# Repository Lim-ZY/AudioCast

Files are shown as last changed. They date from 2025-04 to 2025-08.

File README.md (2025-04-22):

# AudioCast: Enabling Ubiquitous Connectivity for Embedded Systems through Audio-Broadcasting Low-power Tags

banner

## Overview

Wireless connectivity challenges hinder the deployment of embedded systems. We introduce AudioCast to address two critical issues: spectrum scarcity-induced contention and high power consumption in transmitters. The widespread availability of broadcast radio receivers (for example, FM radios using the 88–108 MHz spectrum) and access to underutilized lower-frequency spectrum motivate the design of AudioCast. The lower-frequency spectrum offers superior radio-wave propagation characteristics, exhibiting at least 10× lower path loss than the 2.4 GHz and 5 GHz Industrial, Scientific, and Medical (ISM) bands while avoiding congestion and interference. These properties enable reliable and long-distance communication, even for weakly radiated signals. AudioCast builds on these properties and the unique negative resistance of a tunnel diode.

AudioCast rethinks the architecture of radio transmitters using a tunnel diode oscillator to generate carrier signals and self-modulate them with baseband signals. This results in frequency-modulated transmissions at an overall power consumption below 200 μW. Unlike related systems based on the backscatter mechanism, AudioCast does not require an externally generated carrier or rely on ambient signals. We argue that AudioCast represents an example of a new class of transmitters which we conceptualize as Beyond-Backscatter transmitters. Through experiments, we demonstrate that AudioCast achieves a transmission range of up to 130 m in line-of-sight and tens of meters in non-line-of-sight conditions respectively. These transmissions are decodable by ubiquitous commodity FM receivers in cars, homes, and phones. We evaluate AudioCast through theoretical analysis, benchtop experiments, and urban/indoor field deployments. Additionally, we prototype and demonstrate novel applications, including low-power voice transmissions and hand gesture communication, enabled by AudioCast’s range and power efficiency.

## Repository Organization

```
├── LICENSE                
├── README.md
├── frequency_scanner         # Utility to scan unallocated FM frequencies
├── hardware                  # PCB hardware design files for baseband generator and frontend
├── assets                    # Images, videos, posters, etc.
└── transmitter_firmware      # Firmware code for baseband generator, FM tuner, etc.
```

## AudioCast System Preview

### FM Modulation vs Mixing

With increasing frequency of baseband / message signal, the value of the modulation index reduces and it becomes narrowband frequency modulation. A narrowband frequency modulation can be approximated as a mixing process, with upper sidebands becoming negligible which is shown in the following video:

https://github.com/user-attachments/assets/ccb81c37-590c-4e0f-b894-82cb153416e6

Alternatively: Watch it [here](https://www.youtube.com/watch?v=7RvvvsP36FI)

### Indoor NLoS Audio Evaluation

Non-line-of-sight (NLoS) evaluation of AudioCast transmitter, showing the transmitted audio snippets and corresponding received audio snippets at 7 different locations. We transmitted audio snippets of 30s but for the video we depict only 5s to make it brief. Furthermore, the calculated PESQ score for evaluating the received audio quality is also shown in the following video:

https://github.com/user-attachments/assets/ebbb9d8d-553b-4ae6-ada7-a8c252bf67cc

Alternatively: Watch it [here](https://www.youtube.com/watch?v=k4Gf5YFvplg)

> The above videos can also be previewed [here](./assets/videos/).

## Publications

1. [**ACM IMWUT (UbiComp) '25**](https://doi.org/10.1145/3729471) - *AudioCast: Enabling Ubiquitous Connectivity for Embedded Systems through Audio-Broadcasting Low-power Tags*
   > **Full paper** to appear in IMWUT - June '25: **Vol. 9, No. 2, Article 27** and to be presented at ACM UbiComp '25 in Espoo, Finland.
    <details>
    <summary>Click to expand citation</summary>

    ```
    @article{audiocast_imwut25,
        author = {Reddy, C. Rajashekar; Shah, Dhairya Jigar; Ang, Nobel and Varshney, Ambuj (to appear)},
        title = {AudioCast: Enabling Ubiquitous Connectivity for Embedded Systems through Audio-Broadcasting Low-power Tags},
        journal = {IMWUT},
        year = {2025},
        issue_date = {June 2025},
        publisher = {Association for Computing Machinery},
        address = {New York, NY, USA},
        volume = {9},
        number = {2},
        url = {https://doi.org/10.1145/3729471},
        doi = {10.1145/3729471},
        articleno = {27},
        numpages = {32},
    }
    ```

    </details>

 2. [**ACM MobiSys '25**](https://www.sigmobile.org/mobisys/2025/) - *Enabling Ubiquitous Connectivity for Embedded Systems through Audio-Broadcasting Low-power Tags*
    > **Demo** to appear at MobiSys '25 in Anaheim, California, US.
    <details>
    <summary>Click to expand citation</summary>

    ```
    @inproceedings{audiocast_mobisys25,
        author = {Reddy, C. Rajashekar and Shah, Dhairya Jigar and Varshney, Ambuj (to appear)},
        title = {Enabling Ubiquitous Connectivity for Embedded Systems through Audio-Broadcasting Low-power Tags},
        year = {2025},
        publisher = {Association for Computing Machinery},
        address = {New York, NY, USA},
        numpages = {2},
        location = {Anaheim, California, US},
        series = {MOBISYS '25}
    }
    ```
    </details>

 3. [**ACM ENSsys '23**](https://dl.acm.org/doi/10.1145/3628353.3628546) - *Beyond Broadcasting: Revisiting FM Frequency-band for Providing Connectivity to Next Billion Devices*
    > **Paper** presented at EnSsys '23 Workshop which has held in conjunction with ACM SenSys '23 in Istanbul, Turkey. AudioCast builds on this early work.
    <details>
    <summary>Click to expand citation</summary>
    
    ```
    @inproceedings{tunnelradio_enssys23,
        author = {Reddy, C. Rajashekar and Gulati, Manoj and Varshney, Ambuj},
        title = {Beyond Broadcasting: Revisiting FM Frequency-band for Providing Connectivity to Next Billion Devices},
        year = {2023},
        isbn = {9798400704383},
        publisher = {Association for Computing Machinery},
        address = {New York, NY, USA},
        url = {https://doi.org/10.1145/3628353.3628546},
        doi = {10.1145/3628353.3628546},
        booktitle = {Proceedings of the 11th International Workshop on Energy Harvesting \& Energy-Neutral Sensing Systems},
        pages = {30–36},
        numpages = {7},
        keywords = {FM communication, Internet of Things (IoT), Low-Power Communication, Tunnel Diodes},
        location = {Istanbul, Turkiye},
        series = {ENSsys '23}
    }
    ```

## Contributors and Team

AudioCast is developed and maintained by the following researchers from the [WEISER group](https://weiserlab.github.io/ambuj/) from the School of Computing, National University of Singapore (NUS). 

1. [C. Rajashekar Reddy](https://github.com/rez39)
2. [Dhairya Shah](https://github.com/dhairyashah1/)
3. [Prof. Ambuj Varshney](https://github.com/weiserlab/)

> Feel free to contact us at [`rajashekar.c@u.nus.edu`](mailto:rajashekar.c@u.nus.edu) or [`dhairya@u.nus.edu`](mailto:dhairya@u.nus.edu) for any questions or suggestions.

## Acknowledgements

We acknowledge Nobel Ang, [Yuvraj Singh Bhadauria](https://github.com/UvrajSB) and [Manoj Gulati](https://github.com/manojgulati) for their assistance and support during the early stages of this work.

## Funding

This research is fully supported by the Advanced Research and Technology Innovation Centre **(ARTIC)** at the National University of Singapore. In addition, some parts of this work are supported by a **Tier 1 grant** from Ministry of Education. It is also supported by a **Startup Grant** from ODPRT and an unrestricted gift from Google through their **Research Scholar Program**, all of which are hosted at the National University of Singapore (NUS).

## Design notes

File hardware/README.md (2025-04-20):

# Hardware Design Files

This folder contains PCB design files for the hardware: baseband generator and tunnel-diode oscillator frontend (TDO) used in AudioCast.

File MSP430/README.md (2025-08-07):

Connections from MSP430 to Si4713:

External Pullup Resistors required for I2C

MSP430 -> Si4713

Data: P1.2 -> LIN/RIN

SDA: P1.6 -> SDA

SCL: P1.7 -> SCL

RST: RST -> RST

VCC: VCC -> VIN

GND: GND -> GND

## Building

### Code Composer Studio (Windows)

1. Go to the taskbar and select File.
2. Select _Import Project(s)..._ and navigate to the MSP430 folder before selecting _Finish_.
3. Right click on the AudioCast folder and select properties.
4. Navigate to _MSP430 Compiler -> Processor Options_ and set:
    - Silicon version = mspx
    - Code memory model = small
    - Data memory model = small
5. Navigate to _MSP430 Compiler -> Optimization_ and set:
    - Optimization level = 4 - Whole Program Optimizations
    - Speed vs. size trade-offs = 0 (size)
6. Navigate to _MSP430 Compiler -> Advanced Options -> Language Options_ and set
    Level of printf/scanf support required = full
7. Navigate to _MSP430 Linker -> Basic Options_ and set:
    - Heap size for C/C++ dynamic memory allocation = 352
    - Set C system stack size = 240
8. Select run and click _Flash Project_.

### Code Composer Studio (Linux, macOS)

TBD

### PlatformIO 

TBD

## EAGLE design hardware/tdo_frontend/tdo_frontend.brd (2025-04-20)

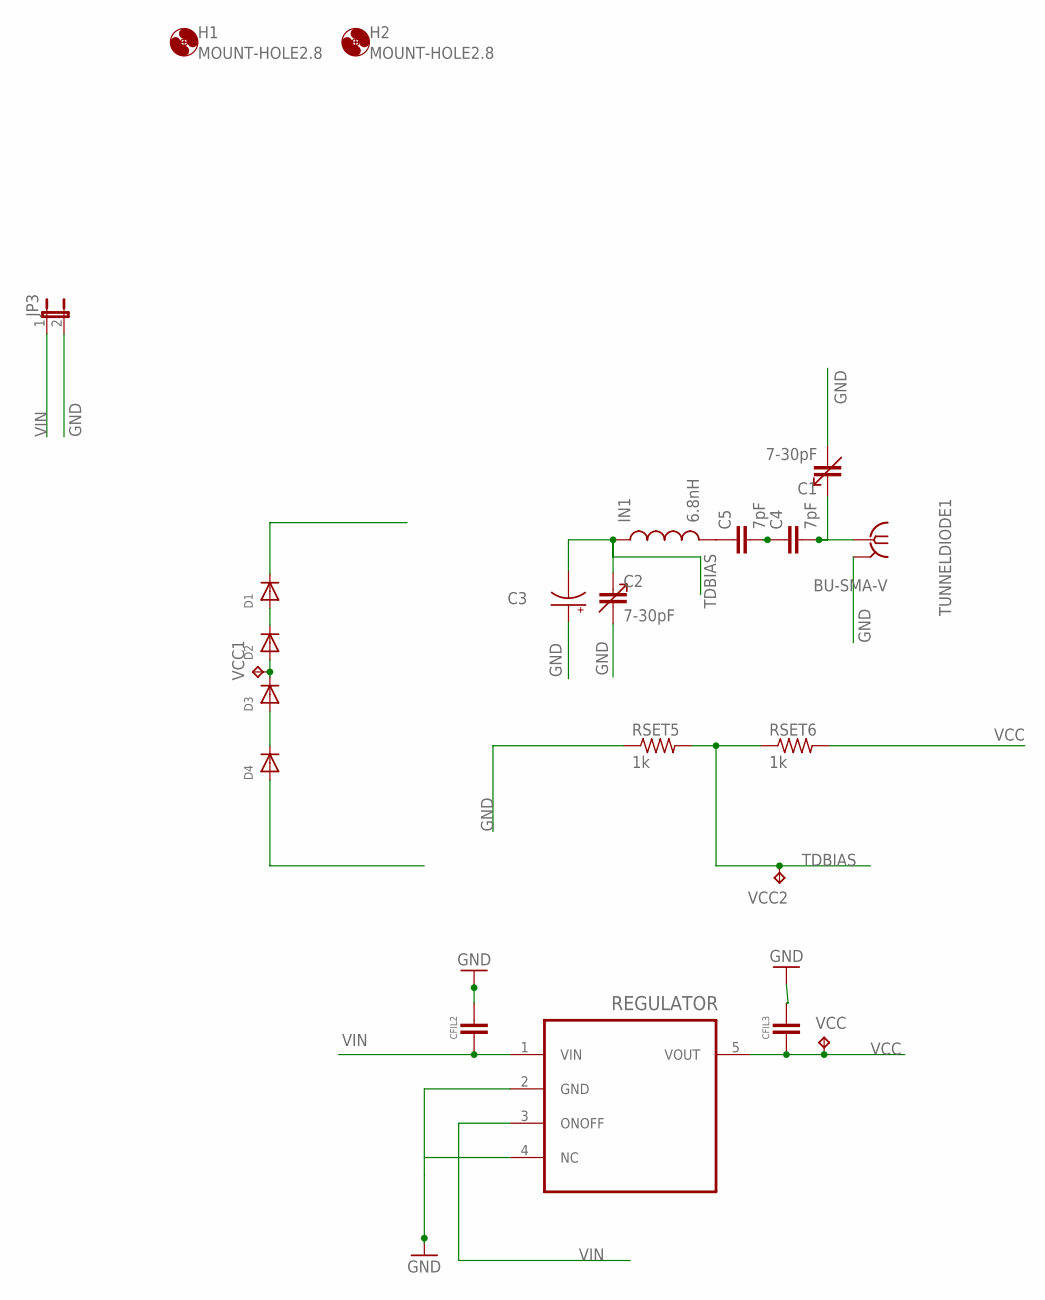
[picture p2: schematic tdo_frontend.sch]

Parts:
C1, C2: 7-30pF; CTZ3
C3: .22F-SUPERCAP; DSK-RADIAL-4.8MM
C4, C5: 7pF; C0603
CFIL2, CFIL3: 0805_1; 0805_1PRIMARY
D1, D2, D3, D4: DIODEDO-1N4148; DO-1N4148
H1, H2: MOUNT-HOLE2.8; 2,8
IN1: 6.8nH; 0603_1PRIMARY
JP3: JP1E; JP1
REGULATOR: S-1313B20; SOT23-5
RSET5, RSET6: 1k; R0603
TUNNELDIODE1: BU-SMA-V
VCC, VCC1, VCC2: TPPAD1-17; P1-17

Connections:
ANT2: C1.+ (3), C4.2, TUNNELDIODE1.1
GND: C1.- (4), C2.- (4), C3.+, CFIL2.2, CFIL3.2, JP3.2, REGULATOR.2 (GND), REGULATOR.4 (NC), RSET5.1, TUNNELDIODE1.2, TUNNELDIODE1.3 (2), TUNNELDIODE1.4 (2), TUNNELDIODE1.5 (2)
unnamed: D3.A, D4.C
unnamed: C4.1, C5.2
unnamed: D2.A, D3.C, VCC1.TP
unnamed: C5.1, IN1.2
unnamed: D1.A, D2.C
TDBIAS: C2.+ (3), C3.-, IN1.1, RSET5.2, RSET6.1, VCC2.TP
VCC: CFIL3.1, REGULATOR.5 (VOUT), RSET6.2, VCC.TP
VIN: CFIL2.1, JP3.1, REGULATOR.1 (VIN), REGULATOR.3 (ONOFF)

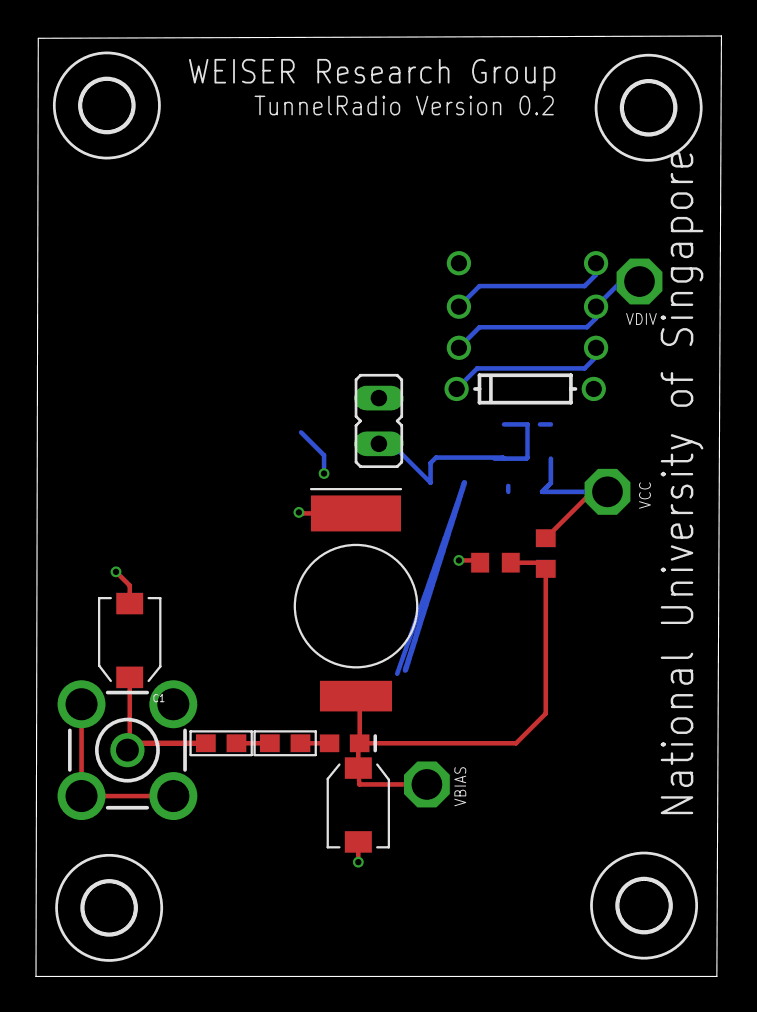
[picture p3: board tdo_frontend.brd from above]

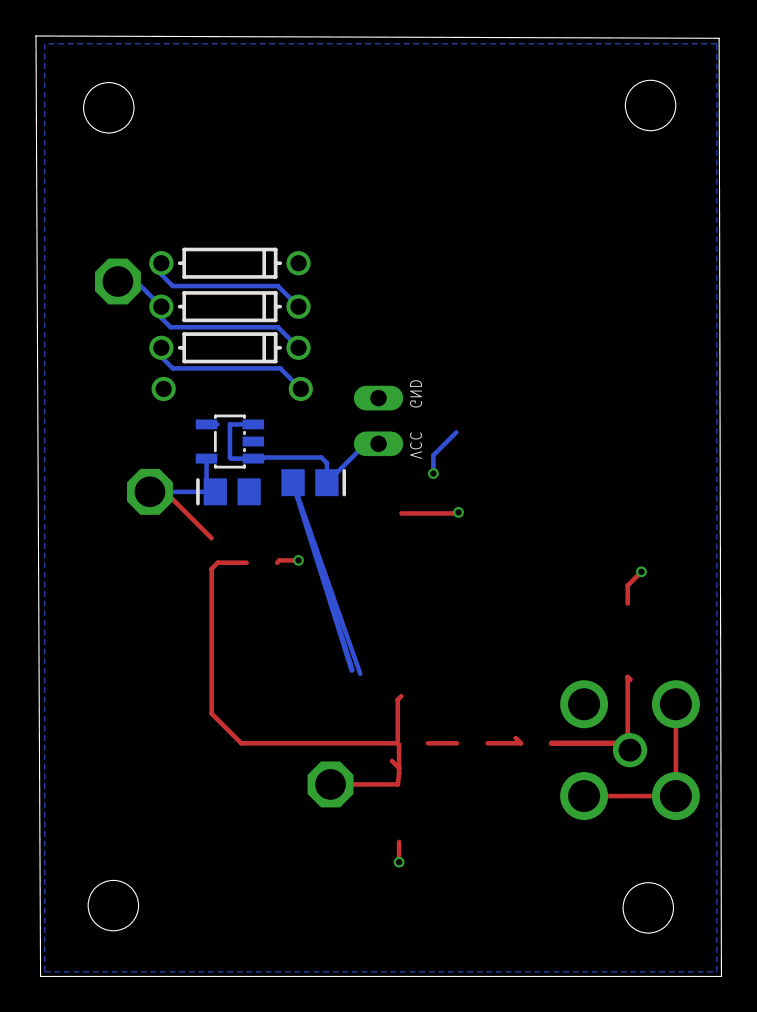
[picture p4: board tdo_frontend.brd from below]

Board: 2 copper layers, 38.1 x 52.2 mm, 24 parts (6 on the bottom side), 10 nets.

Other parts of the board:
H3, H4: MOUNT-HOLE2.8; 2,8

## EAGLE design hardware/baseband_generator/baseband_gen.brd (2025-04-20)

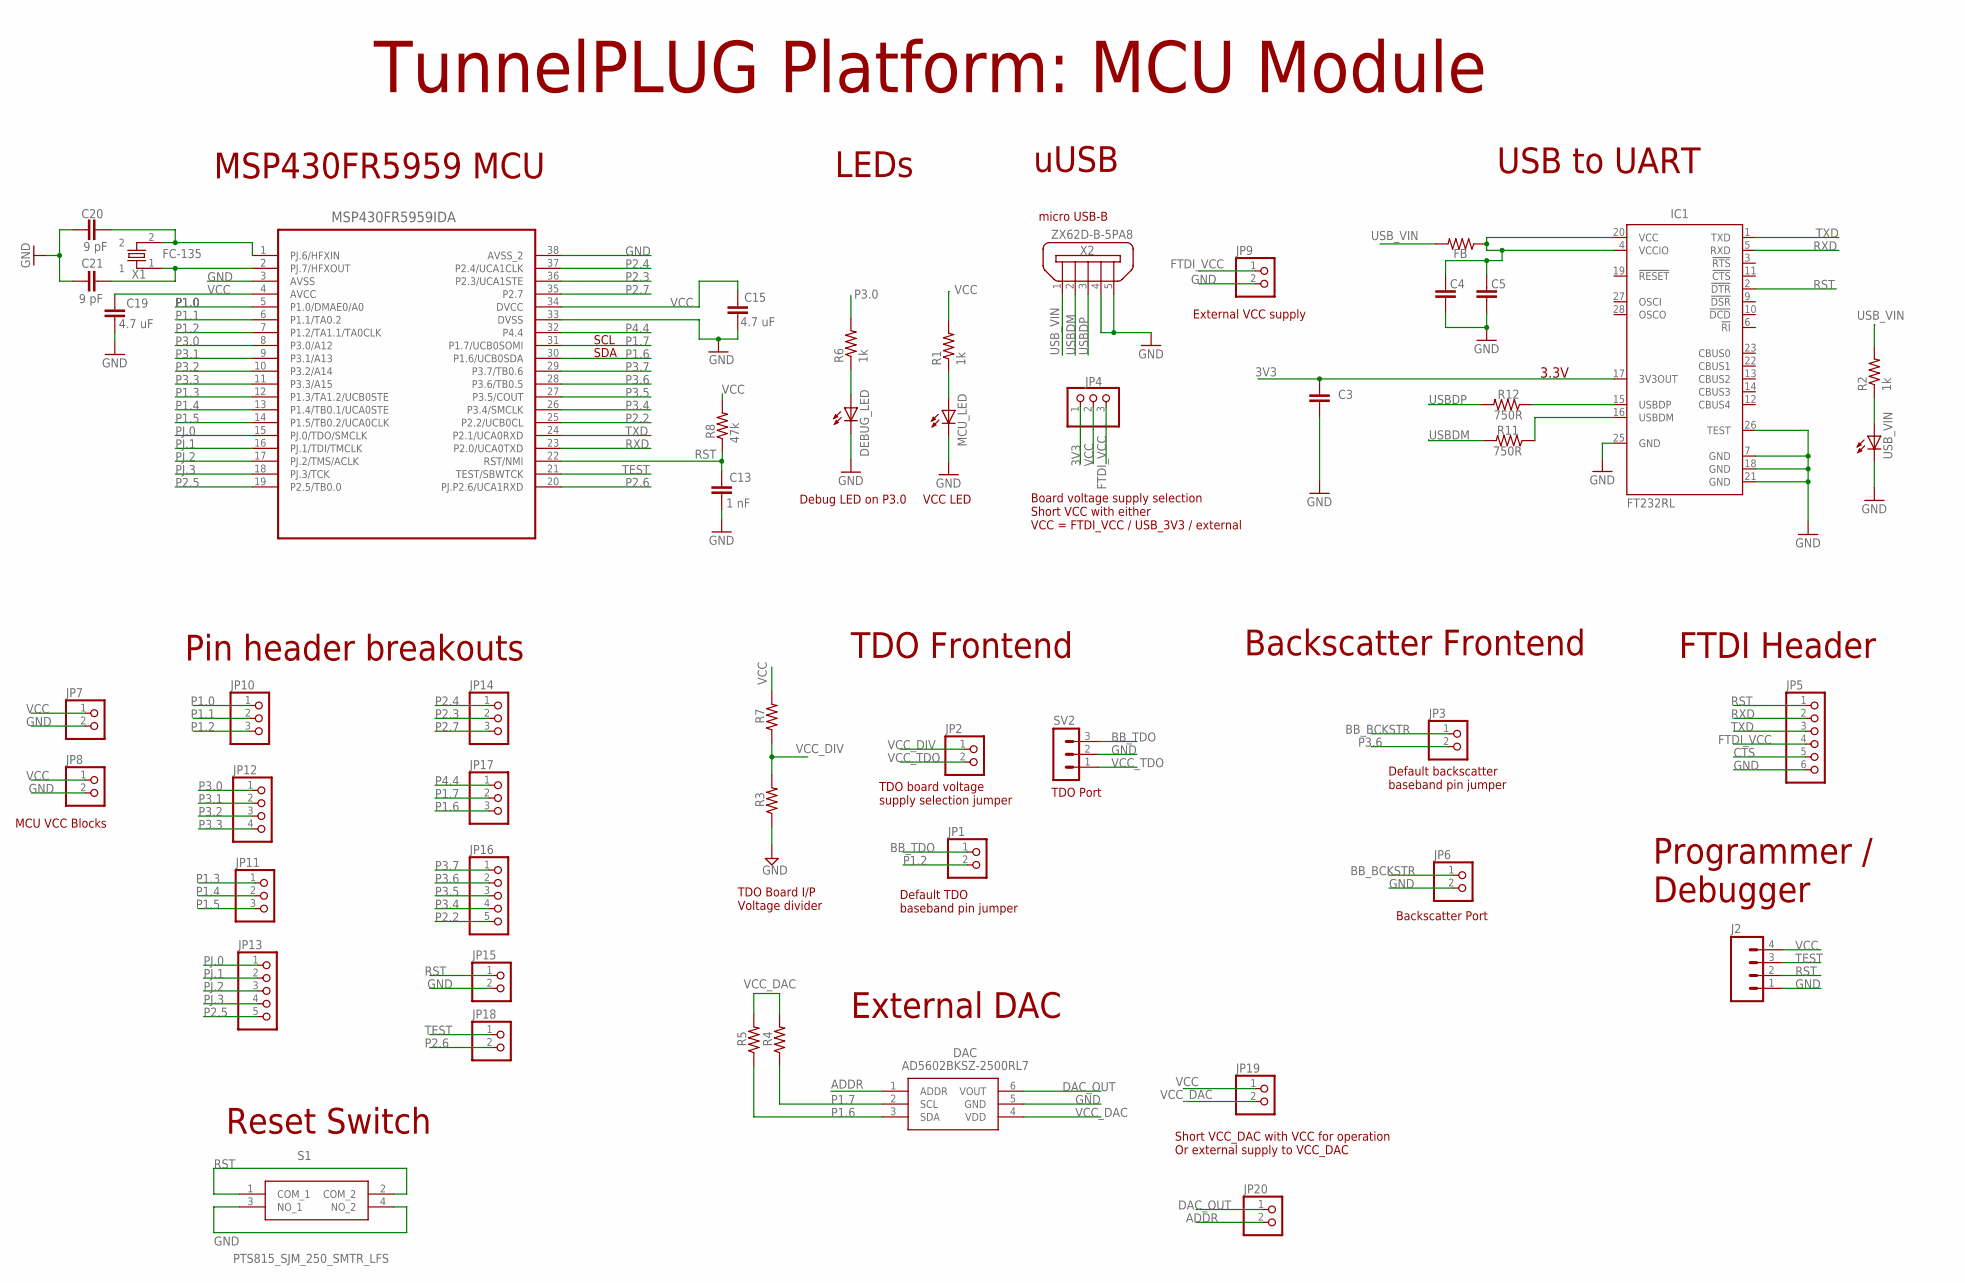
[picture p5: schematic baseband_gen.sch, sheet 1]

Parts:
C3, C4, C5: 0805_1; 0805_1PRIMARY
C13: 1 nF; C0603
C15, C19: 4.7 uF; C0603
C20, C21: 9 pF; C0603
DAC: AD5602BKSZ-2500RL7; SOT65P210X110-6N
DEBUG_LED: LED0603; LED-0603
FB: RESISTOR0805-RES; 0805
IC1: FT232RL; SSOP28
J2: MHDR1X4_1; MHDR1X4_1PRIMARY
JP1, JP2, JP3: PINHD-1X2/LOCK; 1X02/LOCK
JP4: PINHD-1X3/LOCK; 1X03/LOCK
JP5: PINHD-1X6/90; 1X06/90
JP6, JP7, JP8, JP9, JP15, JP18, JP19, JP20: PINHD-1X2; 1X02
JP10, JP11, JP14, JP17: PINHD-1X3; 1X03
JP12: PINHD-1X4; 1X04
JP13, JP16: PINHD-1X5; 1X05
MCU_LED: LED0603; LED-0603
R1, R2, R6: 1k; 0805
R3, R4, R5, R7: R-US_R0603; R0603
R8: 47k; 0805
R11, R12: 750R; 0805
S1: PTS815_SJM_250_SMTR_LFS; PTS815SJM250SMTRLFS
SV2: MA03-1
U2: MSP430FR5739IDAMSP430FR5959IDA; SOP65P810X120-38N
USB_VIN: LED0603; LED-0603
X1: FC-135; FC-135_1PRIMARY
X2: ZX62D-B-5PA8

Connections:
3V3: C3.1, IC1.17 (3V3OUT), JP4.1
ADDR: DAC.1 (ADDR), JP20.2
BB_BCKSTR: JP3.1, JP6.1
BB_TDO: JP1.1, SV2.3
CTS: JP5.5
DAC_OUT: DAC.6 (VOUT), JP20.1
FTDI_VCC: JP4.3, JP5.4, JP9.1
GND: C3.2, C4.2, C5.2, C13.2, C15.1, C19.2, C20.2, C21.2, DAC.5 (GND), DEBUG_LED.C, IC1.7 (GND), IC1.18 (GND), IC1.21 (GND), IC1.25 (GND), IC1.26 (TEST), J2.1, JP5.6, JP6.2, JP7.2, JP8.2, JP9.2, JP15.2, MCU_LED.C, R3.1, S1.3 (NO_1), S1.4 (NO_2), SV2.2, U2.3 (AVSS), U2.33 (DVSS), U2.38 (AVSS_2), USB_VIN.C, X2.4, X2.5
unnamed: C21.1, U2.2 (PJ.7/HFXOUT), X1.1
unnamed: C20.1, U2.1 (PJ.6/HFXIN), X1.2
unnamed: DEBUG_LED.A, R6.1
unnamed: MCU_LED.A, R1.1
unnamed: R2.1, USB_VIN.A
unnamed: C4.1, C5.1, FB.1, IC1.4 (VCCIO), IC1.20 (VCC)
unnamed: IC1.15 (USBDP), R12.1
unnamed: IC1.16 (USBDM), R11.1
P1.0: JP10.1, U2.5 (P1.0/DMAE0/A0)
P1.1: JP10.2, U2.6 (P1.1/TA0.2)
P1.2: JP1.2, JP10.3, U2.7 (P1.2/TA1.1/TA0CLK)
P1.3: JP11.1, U2.12 (P1.3/TA1.2/UCB0STE)
P1.4: JP11.2, U2.13 (P1.4/TB0.1/UCA0STE)
P1.5: JP11.3, U2.14 (P1.5/TB0.2/UCA0CLK)
P1.6: DAC.3 (SDA), JP17.3, R5.1, U2.30 (P1.6/UCB0SDA)
P1.7: DAC.2 (SCL), JP17.2, R4.1, U2.31 (P1.7/UCB0SOMI)
P2.2: JP16.5, U2.25 (P2.2/UCB0CL)
P2.3: JP14.2, U2.36 (P2.3/UCA1STE)
P2.4: JP14.1, U2.37 (P2.4/UCA1CLK)
P2.5: JP13.5, U2.19 (P2.5/TB0.0)
P2.6: JP18.2, U2.20 (PJ.P2.6/UCA1RXD)
P2.7: JP14.3, U2.35 (P2.7)
P3.0: JP12.1, R6.2, U2.8 (P3.0/A12)
P3.1: JP12.2, U2.9 (P3.1/A13)
P3.2: JP12.3, U2.10 (P3.2/A14)
P3.3: JP12.4, U2.11 (P3.3/A15)
P3.4: JP16.4, U2.26 (P3.4/SMCLK)
P3.5: JP16.3, U2.27 (P3.5/COUT)
P3.6: JP3.2, JP16.2, U2.28 (P3.6/TB0.5)
P3.7: JP16.1, U2.29 (P3.7/TB0.6)
P4.4: JP17.1, U2.32 (P4.4)
PJ.0: JP13.1, U2.15 (PJ.0/TDO/SMCLK)
PJ.1: JP13.2, U2.16 (PJ.1/TDI/TMCLK)
PJ.2: JP13.3, U2.17 (PJ.2/TMS/ACLK)
PJ.3: JP13.4, U2.18 (PJ.3/TCK)
RST: C13.1, IC1.2 (!DTR), J2.2, JP5.1, JP15.1, R8.1, S1.1 (COM_1), S1.2 (COM_2), U2.22 (RST/NMI)
RXD: IC1.5 (RXD), JP5.2, U2.23 (P2.0/UCA0TXD)
TEST: J2.3, JP18.1, U2.21 (TEST/SBWTCK)
TXD: IC1.1 (TXD), JP5.3, U2.24 (P2.1/UCA0RXD)
USBDM: R11.2, X2.2
USBDP: R12.2, X2.3
USB_VIN: FB.2, R2.2, X2.1
VCC: C15.2, C19.1, J2.4, JP4.2, JP7.1, JP8.1, JP19.1, R1.2, R7.2, R8.2, U2.4 (AVCC), U2.34 (DVCC)
VCC_DAC: DAC.4 (VDD), JP19.2, R4.2, R5.2
VCC_DIV: JP2.1, R3.2, R7.1
VCC_TDO: JP2.2, SV2.1

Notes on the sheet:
MSP430FR5959 MCU
LEDs
TunnelPLUG Platform: MCU Module
uUSB
USB to UART
FTDI Header
3.3V
Board voltage supply selection Short VCC with either VCC = FTDI_VCC / USB_3V3 / external
TDO Frontend
Backscatter Frontend
Debug LED on P3.0
micro USB-B
VCC LED
Pin header breakouts
External VCC supply
Default backscatter baseband pin jumper
Default TDO baseband pin jumper
TDO board voltage supply selection jumper
TDO Port
Backscatter Port
TDO Board I/P Voltage divider
MCU VCC Blocks
Reset Switch
External DAC
Short VCC_DAC with VCC for operation Or external supply to VCC_DAC
SCL
SDA
Programmer / Debugger

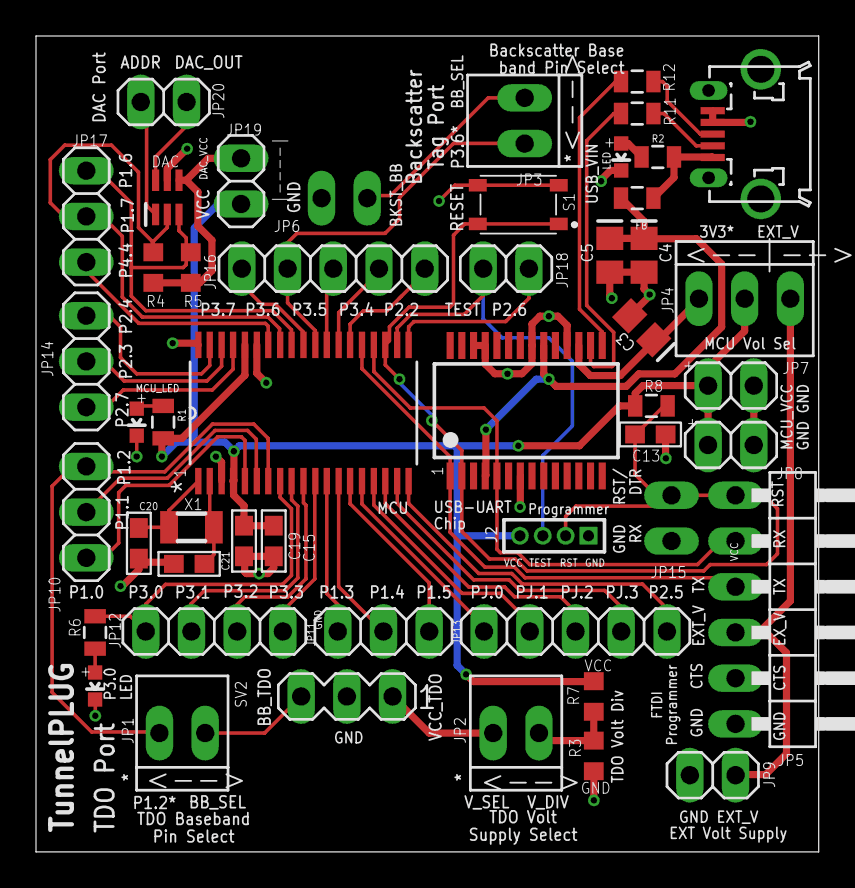
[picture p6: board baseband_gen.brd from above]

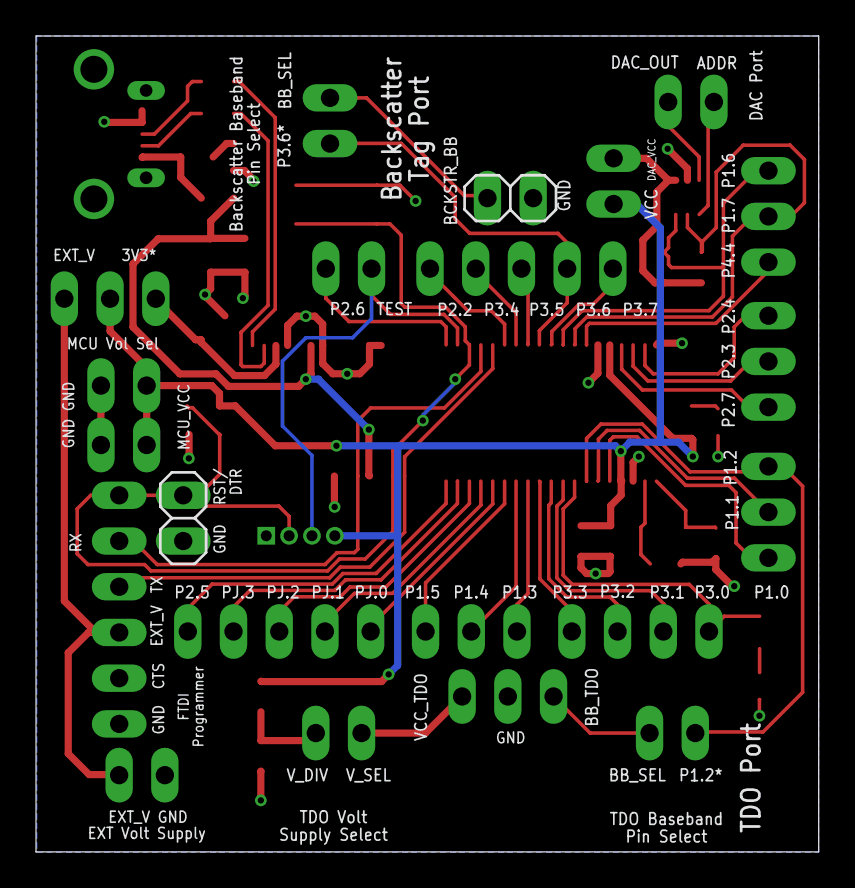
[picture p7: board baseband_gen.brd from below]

Board: 2 copper layers, 43.5 x 45.3 mm, 50 parts (2 on the bottom side), 53 nets.

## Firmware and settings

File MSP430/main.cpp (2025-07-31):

/* #############################################################################################
* Authors     : Lim Zi Yang, Yao Hejun
* Emails      : e1398962@u.nus.edu, e1113781@u.nus.edu
################################################################################################
ADAPTED FROM AUDIOCAST FOR MSP430
* Baseband Audio Generator for AudioCast Transmitter*

* Description : This sketch encodes sensor / fixed data in the form of audio signals which serves 
as a baseband signal for AudioCast transmitter. 
* Additional  : It builds on the ggwave library by ggerganov: https://github.com/ggerganov/ggwave/tree/master/examples/arduino-tx 
* Framework   : Platform IO
* Build Target: This sketch currently comples on ESP32-WROOM-32 (Devkit and NodeMCU), Check "platform.ini".
    - However, it works with other platformio compatible platforms like - Arduino Uno R3, Arduino Nano RP2040 Connect, etc.

* Receiver    : AudioCast uses a spectrum analyser to listen to the data encoded audio broadcasted by AudioCast.
                Further, the freely available "waver" app can be used to decode the data by listening to these transmissions
    - Web:     https://waver.ggerganov.com
    - Android: https://play.google.com/store/apps/details?id=com.ggerganov.Waver
    - iOS:     https://apps.apple.com/us/app/waver-data-over-sound/id1543607865
* Make sure to enable the "Fixed-length" option in "Waver"'s settings and set the number of bytes to 
be equal to "payloadLength" used in the sketch.
################################################################################################*/

#include "driverlib.h"
#include <string.h>
#include "ggwave/ggwave.h"
#include "ggwave/pstr.h"
#include "SI4713/Adafruit_Si4713.h"

// ggwave params
#define sPerFrame 128
#define sRate     6000
#define TX_PROT   GGWAVE_PROTOCOL_MT_FASTEST
#define PL        8

// ggwave functions
#define PSTR(s) (s)
#define strcpy_P strcpy
#define P(str) (strcpy_P(txt, PSTR(str)), txt)

// SI4713 params
#define _BV(n) (1 << n)
#define RESETPIN BIT3
#define FMSTATION 10230                // 10230 == 102.30 MHz

// MSP430 I2C params
#define SLAVE_ADDRESS SI4710_ADDR1

// Global instances
GGWave ggwave;
char txt[64];
Adafruit_Si4713 radio = Adafruit_Si4713(RESETPIN);

// FUNCTIONS======================================================================
void ser_print(const char* message) {
    while (*message != '\0') {
        while (!(UCA0IFG & UCTXIFG));          // Wait for UART TX buffer to be ready
        UCA0TXBUF = *message++;                // Send character and advance pointer
        __delay_cycles(1000);          // Small delay
    }
}

void ser_printa(uint8_t* array, int array_len) {
    char buf[16];
    int i;
    for (i = 0; i < array_len; i++) {
        sprintf(buf, "%x ", array[i]);
        ser_print(buf);
    }
    ser_print("\n");
}

void delay_ms(unsigned int ms) {
    while (ms) {
        __delay_cycles(8000);
        ms--;
    }
}

void generate_tone(uint16_t freq_hz) {   
    // Set frequency
    const uint32_t SMCLK_FREQ = 8000000; // CLK adjusted to 8MHz in init_msp()
    const uint16_t timer_period = (SMCLK_FREQ + (freq_hz/2)) / freq_hz - 1; //(SMCLK_FREQ / freq_hz) - 1;
    const uint16_t duty_cycle = timer_period / 2;

    //Generate PWM - Timer runs in Up-Down mode
    Timer_A_outputPWMParam param = {0};
    param.clockSource = TIMER_A_CLOCKSOURCE_SMCLK;
    param.clockSourceDivider = TIMER_A_CLOCKSOURCE_DIVIDER_1;
    param.timerPeriod = timer_period; //changed
    param.compareRegister = TIMER_A_CAPTURECOMPARE_REGISTER_1;
    param.compareOutputMode = TIMER_A_OUTPUTMODE_RESET_SET;
    param.dutyCycle = duty_cycle; //changed
    Timer_A_outputPWM(TIMER_A1_BASE, &param);
}

void init_msp(void) {
    //--Stop WDT
    WDT_A_hold(WDT_A_BASE);

    //--Setup UART A0
    UCA0CTLW0 |= UCSWRST;                     // put eUSCI into reset
    UCA0CTLW0 |= UCSSEL__SMCLK;               // BRCLK = SMCLK
    // Baud Rate calculation
    // 8000000/(16*9600) = 52.083
    // Fractional portion = 0.083
    // User's Guide Table 21-4: UCBRSx = 0x04
    // UCBRFx = int ( (52.083-52)*16) = 1
    UCA0BR0 = 52;                             // 8000000/16/9600
    UCA0BR1 = 0x00;
    UCA0MCTLW |= UCOS16 | UCBRF_1;            // OS16 and modulation

    //--Configure GPIO
    P2SEL1 |= BIT0 | BIT1;                    // USCI_A0 UART operation   
    P2SEL0 &= ~(BIT0 | BIT1);                 // (&= ~ clear the bit)
    //--P1.2 as PWM output (for generate_tone())
    GPIO_setAsPeripheralModuleFunctionOutputPin(
        GPIO_PORT_P1,
        GPIO_PIN2,
        GPIO_PRIMARY_MODULE_FUNCTION
        );

    //--Startup clock system with max DCO setting ~8MHz (for UART)
    CSCTL0_H = CSKEY >> 8;                    // Unlock clock registers
    CSCTL1 = DCOFSEL_3 | DCORSEL;             // Set DCO to 8MHz
    CSCTL2 = SELA__VLOCLK | SELS__DCOCLK | SELM__DCOCLK;
    CSCTL3 = DIVA__1 | DIVS__1 | DIVM__1;     // Set all dividers
    CSCTL0_H = 0;                             // Lock CS registers

    UCA0CTLW0 &= ~UCSWRST;                    // put eUSCI out of reset

    //--Setup I2C
    P1SEL1 |= BIT6 | BIT7;                    // I2C pins in secondary module function
    P1DIR |= RESETPIN;                        // RST pin for SI4713
    UCB0CTLW0 = UCSWRST;                      // Enable SW reset
    UCB0CTLW0 |= UCMODE_3 | UCMST | UCSSEL__SMCLK | UCSYNC; // I2C master mode, SMCLK
    UCB0BRW = 80;                            // fSCL = SMCLK/160 = ~100kHz
    UCB0I2CSA = SLAVE_ADDRESS;                   // Slave Address
    UCB0CTLW0 &= ~UCSWRST;                    // Clear SW reset, resume operation
    UCB0IE |= UCNACKIE;

    PM5CTL0 &= ~LOCKLPM5;                     // turn on I/O
    // char buf[32];
    // sprintf(buf, "%lu", CS_getSMCLK());
    // ser_print(buf);
    ser_print("MSP INIT SUCCESS\n");
}

void init_radio(void) {
    char buf[16];

    ser_print("Radio Begin=======\n");

    if (! radio.begin()) {  // begin with address 0x63 (CS high default)
        ser_print("Couldn't find radio?\n");
        while (1);
    }

    ser_print("\nSet TX power");
    radio.setTXpower(115);  // dBuV, 88-115 max

    ser_print("\nTuning into ");
    sprintf(buf, "%d.", FMSTATION/100);
    ser_print(buf);
    sprintf(buf, "%d\n", FMSTATION % 100);
    ser_print(buf);
    radio.tuneFM(FMSTATION); // 102.3 mhz

    // This will tell you the status in case you want to read it from the chip
    radio.readTuneStatus();
    ser_print("\tCurr freq: ");
    sprintf(buf, "%d.", radio.currFreq); 
    ser_print(buf);
    ser_print("\tCurr freqdBuV:"); 
    sprintf(buf, "%d.", radio.currdBuV); 
    ser_print(buf);
    ser_print("\tCurr ANTcap:"); 
    sprintf(buf, "%d. \n", radio.currAntCap); 
    ser_print(buf);

    radio.setGPIOctrl(_BV(1) | _BV(2));  // set GP1 and GP2 to output
}

void init_ggwave(void) {
    //initialise ggwave
    ggwave.setLogFile(nullptr);

    auto p = GGWave::getDefaultParameters();

    // Adjust the "ggwave" parameters to your needs.
    // Make sure that the "payloadLength" parameter matches the one used on the transmitting side.
    p.payloadLength   = PL;
    p.sampleRateInp   = sRate;
    p.sampleRateOut   = sRate;
    p.sampleRate      = sRate;
    p.samplesPerFrame = sPerFrame;
    p.sampleFormatInp = GGWAVE_SAMPLE_FORMAT_I16;
    p.sampleFormatOut = GGWAVE_SAMPLE_FORMAT_U8;
    p.operatingMode   = GGWAVE_OPERATING_MODE_TX | GGWAVE_OPERATING_MODE_TX_ONLY_TONES | GGWAVE_OPERATING_MODE_USE_DSS;

    // Protocols to use for TX
    GGWave::Protocols::tx().only(TX_PROT);

    // Sometimes, the speaker might not be able to produce frequencies in the Mono-tone range of 1-2 kHz.
    // In such cases, you can shift the base frequency up by changing the "freqStart" parameter of the protocol.
    // Make sure that in the receiver (for example, the "Waver" app) the base frequency is shifted by the same amount.
    // Here we shift the frequency by +48 bins. Each bin is equal to 48000/1024 = 46.875 Hz.
    // So the base frequency is shifted by +2250 Hz.
    // GGWave::Protocols::tx()[GGWAVE_PROTOCOL_MT_FASTEST].freqStart += 48;

    // Initialize the ggwave instance and print the memory usage
    if (!ggwave.prepare(p)) {
        ser_print("PREPARE FAILED\n");
    } else {
        ser_print("PREPARE SUCCESS\n");
    }

    ser_print("Instance initialized successfully!\n");
}

void send_text(GGWave &ggwave, const char * text, GGWave::TxProtocolId protocolId) {
    ser_print("Sending text...\n");
    if (!ggwave.init(text, protocolId)) {
        ser_print("INIT FAILED\n");
    } else {
        ser_print("INIT SUCCESS\n");
    }

    if (!ggwave.encode()) {
        ser_print("ENCODE FAILED\n");
    } else {
        ser_print("ENCODE SUCCESS\n");
    }

    const auto & protocol = GGWave::Protocols::tx()[protocolId];
    const auto tones = ggwave.txTones();
    const auto duration_ms = protocol.txDuration_ms(sPerFrame, sRate);

    for (auto & curTone : tones) {
        const auto freq_hz = (protocol.freqStart + curTone)*ggwave.hzPerSample();
        generate_tone(freq_hz);
        delay_ms(duration_ms);
    }
    Timer_A_stop(TIMER_A1_BASE);
}

void main (void)
{    
    init_msp();

    init_radio();

    init_ggwave();

    int i = 0;
    char tmp[8];
    while (true) {
        sprintf(tmp, "%03d%s", i, "ABCD");
        ser_print(tmp);
        send_text(ggwave, P(tmp), TX_PROT);
        __delay_cycles(8000000);
        i++;
    }

    // changed heap size from 160 to 352 and stack size to 240
    // changed printf-support to full
}

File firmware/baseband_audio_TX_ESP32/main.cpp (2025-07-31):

/* #############################################################################################
* Authors     : C. Rajashekar Reddy, Dhairya Shah
* Emails      : rajashekar.c@u.nus.edu, dhairya@u.nus.edu
################################################################################################
* Baseband Audio Generator for AudioCast Transmitter*

* Description : This sketch encodes sensor / fixed data in the form of audio signals which serves 
as a baseband signal for AudioCast transmitter. 
* Additional  : It builds on the ggwave library by ggerganov: https://github.com/ggerganov/ggwave/tree/master/examples/arduino-tx 
* Framework   : Platform IO
* Build Target: This sketch currently comples on ESP32-WROOM-32 (Devkit and NodeMCU), Check "platform.ini".
    - However, it works with other platformio compatible platforms like - Arduino Uno R3, Arduino Nano RP2040 Connect, etc.

* Receiver    : AudioCast uses a spectrum analyser to listen to the data encoded audio broadcasted by AudioCast.
                Further, the freely available "waver" app can be used to decode the data by listening to these transmissions
    - Web:     https://waver.ggerganov.com
    - Android: https://play.google.com/store/apps/details?id=com.ggerganov.Waver
    - iOS:     https://apps.apple.com/us/app/waver-data-over-sound/id1543607865
* Make sure to enable the "Fixed-length" option in "Waver"'s settings and set the number of bytes to 
be equal to "payloadLength" used in the sketch.
################################################################################################*/

#include <Arduino.h>
#include <ggwave.h>
#include <Wire.h>
#include <iostream>
#include <cstring>
#include <string>

#include "DFRobot_VEML7700.h"
#include <SPI.h>
#include <Adafruit_Si4713.h>

#define RESETPIN 4

#define FMSTATION 10230      // 10230 == 102.30 MHz

Adafruit_Si4713 radio = Adafruit_Si4713(RESETPIN);
// Uncomment the below if you want to transmit LUX data from DFRobot VEML7700 sensor. Additionally you may connect any other sensor and modify
// #define LUX_sensor_data 

String packet_data = "ABCDEF123456" ; //"ABCD"; //each character is 1 byte -> max can send is 15 bytes 16th byte is ending byte

#ifdef LUX_sensor_data
    #include "DFRobot_VEML7700.h"
    DFRobot_VEML7700 als;  
#else
    // memset(txt, 0xff, sizeof(txt));
#endif

/*
 * Instantiate an object to drive the sensor
 */
DFRobot_VEML7700 als;
// Pin configuration
const int kPinLed0    = 32;
const int kPinSpeaker = 33;

const int samplesPerFrame = 128;
const int sampleRate      = 6000;

// Global GGwave instance
GGWave ggwave;

char txt[64];
#define P(str) (strcpy_P(txt, PSTR(str)), txt)

// Helper function to output the generated GGWave waveform via a buzzer
void send_text(GGWave & ggwave, uint8_t pin, const char * text, GGWave::TxProtocolId protocolId) {
    Serial.print(F("Sending text: "));
    Serial.println(text);

    ggwave.init(text, protocolId);
    ggwave.encode();

    const auto & protocol = GGWave::Protocols::tx()[protocolId];
    const auto tones = ggwave.txTones();
    const auto duration_ms = protocol.txDuration_ms(ggwave.samplesPerFrame(), ggwave.sampleRateOut());
    for (auto & curTone : tones) {
        const auto freq_hz = (protocol.freqStart + curTone)*ggwave.hzPerSample();
        tone(pin, freq_hz);
        delay(duration_ms);
    }

    noTone(pin);
    digitalWrite(pin, LOW);
}

void setup() {
    Wire.begin(); // debug

    Serial.begin(115200);  // 57600 in other file
    while (!Serial);
    Serial.println("\nI2C Scanner"); //debug

    // debug loop

    for (byte addr = 1; addr < 127; addr++) {
        Wire.beginTransmission(addr);
        if (Wire.endTransmission() == 0) {
            Serial.print("I2C device found at 0x");
            Serial.println(addr, HEX);
        }
        delay(10);
    }

    // pinMode(kPinLed0,    OUTPUT);
    pinMode(kPinSpeaker, OUTPUT);
    als.begin();   // Init
    if (! radio.begin()) {  // begin with address 0x63 (CS high default)
        Serial.println("Couldn't find radio?");
        while (1);
    }

    #ifdef LUX_sensor_data
        als.begin();   // Init
    #else
        // memset(txt, 0xff, sizeof(txt));
    #endif    

    Serial.print("\nSet TX power");
    radio.setTXpower(115);  // dBuV, 88-115 max

    Serial.print("\nTuning into "); 
    Serial.print(FMSTATION/100); 
    Serial.print('.'); 
    Serial.println(FMSTATION % 100);
    radio.tuneFM(FMSTATION); // 102.3 mhz    

    // This will tell you the status in case you want to read it from the chip
    radio.readTuneStatus();
    Serial.print("\tCurr freq: "); 
    Serial.println(radio.currFreq);
    Serial.print("\tCurr freqdBuV:"); 
    Serial.println(radio.currdBuV);
    Serial.print("\tCurr ANTcap:"); 
    Serial.println(radio.currAntCap);

    // begin the RDS/RDBS transmission
    radio.beginRDS();
    radio.setRDSstation("AdaRadio");
    radio.setRDSbuffer( "Adafruit g0th Radio!");

    Serial.println("RDS on!");  

    radio.setGPIOctrl(_BV(1) | _BV(2));  // set GP1 and GP2 to output

    // Initialize "ggwave"
    {
        Serial.println(F("Trying to initialize the ggwave instance"));

        ggwave.setLogFile(nullptr);

        auto p = GGWave::getDefaultParameters();

        // Adjust the "ggwave" parameters to your needs.
        // Make sure that the "payloadLength" parameter matches the one used on the transmitting side.
        p.payloadLength   = 16;
        p.sampleRateInp   = sampleRate;
        p.sampleRateOut   = sampleRate;
        p.sampleRate      = sampleRate;
        p.samplesPerFrame = samplesPerFrame;
        p.sampleFormatInp = GGWAVE_SAMPLE_FORMAT_I16;
        p.sampleFormatOut = GGWAVE_SAMPLE_FORMAT_U8;
        p.operatingMode   = GGWAVE_OPERATING_MODE_TX | GGWAVE_OPERATING_MODE_TX_ONLY_TONES | GGWAVE_OPERATING_MODE_USE_DSS;

        // Protocols to use for TX
        GGWave::Protocols::tx().only(GGWAVE_PROTOCOL_MT_FASTEST);

        // Sometimes, the speaker might not be able to produce frequencies in the Mono-tone range of 1-2 kHz.
        // In such cases, you can shift the base frequency up by changing the "freqStart" parameter of the protocol.
        // Make sure that in the receiver (for example, the "Waver" app) the base frequency is shifted by the same amount.
        // Here we shift the frequency by +48 bins. Each bin is equal to 48000/1024 = 46.875 Hz.
        // So the base frequency is shifted by +2250 Hz.
        //GGWave::Protocols::tx()[GGWAVE_PROTOCOL_MT_FASTEST].freqStart += 48;

        // Initialize the ggwave instance and print the memory usage
        ggwave.prepare(p);
        Serial.println(ggwave.heapSize());

        Serial.println(F("Instance initialized successfully!"));
    }
}
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

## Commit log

2025-04-20 Adds hardware design files, ESP32 firmware and FM whitespace scanner
    [baseband_gen.brd, baseband_gen.sch, tdo_frontend.brd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]
2025-07-31 Final working implementation with I2C

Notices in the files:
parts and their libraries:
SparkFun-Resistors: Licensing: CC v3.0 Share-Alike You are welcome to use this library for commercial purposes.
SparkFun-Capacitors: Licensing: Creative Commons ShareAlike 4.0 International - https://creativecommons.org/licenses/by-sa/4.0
